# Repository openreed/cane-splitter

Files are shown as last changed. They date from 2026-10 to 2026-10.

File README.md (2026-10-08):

# Cane splitter — single-file OpenSCAD model

[中文打印与装配说明](README_CN.md)

All active CAD is in **`cane-splitter.scad`**, with BOSL2 `std.scad` and `screws.scad` for real M4 screw threads, as used by the neighboring reed-guillotine. Install BOSL2 in the OpenSCAD library path. Use the Manifold geometry backend. Select `oboe` for three ways or `bassoon` for four. Three main PETG parts: blade grip, stud-located guide lid with recessed M4 screws, and a threaded protective cap/palm pad.

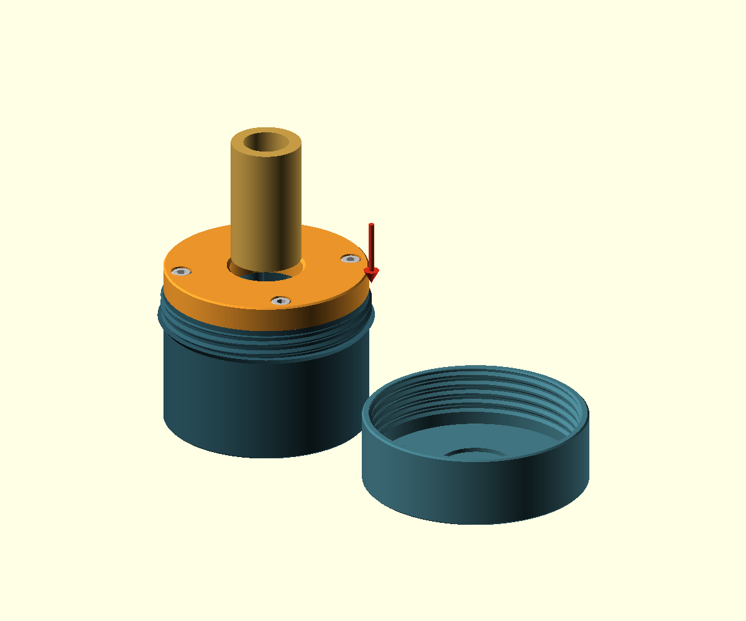
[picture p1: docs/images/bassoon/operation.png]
Top-down cane feed


Cane enters **from the top and moves downward**. The orange-red bevel is the cutting edge; the back extends outward/downward. The earlier incline was reversed and presented a blunt short end to top-down feed. This revision corrects that geometry.

Each complete blade is clamped by one **M2.5 ×10 screw through its round-bottom side notch**, plus washer and captured nut. The slot supports the sides; the screw clamps the printed cheeks and provides positive metal retention. The orange guide lid uses M4 ×12 socket-head screws directly in modeled M4 ×0.7 blind threads. No lid nuts or washers. Three sets per oboe unit; four per bassoon. No blade cutting, drilling or custom metal.

The Ø4.4 mm central guide is 12.3 mm high for oboe and 16.2 mm for bassoon, projecting 6 mm above the fin roots, with a 0.6 mm rounded top edge. One hub/spoke footprint is merged and given 0.8 mm concave root fillets; the rectangular spoke ends are buried at the axis. This gives continuous bottom transitions without exposed square root corners. See the [bottom view](docs/images/oboe/body_bottom.png) and [root detail](docs/images/oboe/root_detail.png). The orange lid guides the cane outside diameter.

Blade clamp holes now lie in straight 8 mm-thick outer support webs, continuous from the bed to the top, instead of raised cylindrical ears. The 3.2 mm central fins and cane exits remain clear. This removes the unsupported local clamping projections when printing upright.

A 0.6 mm ×45° chamfer runs around the orange lid upper edge, body bottom edge and both outer edges of the threaded palm cap. Set `cfg_edge_chamfer` or `--edge-chamfer`; `edge_chamfer_max` derives the limit from the actual counterbore clearance, body wall and cap opening wall, retaining a 0.4 mm lid lip and 1.2 mm shell wall. The current calculated limit is about 1.2 mm. The lid underside retains its flat body seating face.

The orange lid locates on coaxial hollow round studs, Ø7 ×2.5 mm, with 0.4 mm tip chamfers. Bottom sockets are Ø7.3 ×2.8 mm. Its 9 mm thickness leaves a 1.9 mm floor between these sockets and Ø7.6 ×4.3 mm head counterbores. M4 socket heads sit 0.3 mm below the top. Nominal screw engagement is 9.8 mm with 2.2 mm tip clearance. The screw mounts have one D-shaped footprint: a rounded inner end and a 9 mm-wide rectangular wall embedded in the body shell, extruded from the bed to the top. `ring_bolt_r` currently equals `body_r-6`; moving the screw inward automatically lengthens that wall while updating all matching stud and lid holes. See the [inward-position example](docs/images/oboe/ring_mount_inward.png), using body_r −10 and a 1.0 mm chamfer. The optional `connection_coupon` checks the actual PETG/M4 fit. Default BOSL2 internal tolerance is 8G with `$slop=0.04` (0.16 mm added diameter).

The protective cap uses a single-start right-hand trapezoidal thread, pitch 3.6 mm, depth 1 mm and approximately 2.2 engaged turns. An integral annular shoulder stops the cap before it can load the internal screw heads. No snap clips or friction pads. Default radial/axial fit allowances are 0.30/0.15 mm.

- Oboe body including shoulder: Ø63.1 ×50.4 mm including locating studs; stored: Ø66.7 ×62.9 mm. Default OD10, range 9.5–11.5 mm.
- Bassoon body including shoulder: Ø76.9 ×52.6 mm including locating studs; stored: Ø80.5 ×65.1 mm. Default OD25, range 23–27 mm.
- All print parts fit a 180 mm printer. Start with knot-free tubes at least 80 mm long and an inner bore of at least 5.5 mm. Start the splits with the palm pad, then draw the emerging strips evenly from below; short cane can be started and finished along the grain by hand.

Blade dimensions follow the current neighboring `reed-guillotine`: 39 ×19.4 ×0.23 mm, notch width 3/depth 3.8/edge distance 9.6 mm, backing width 7 and total thickness **0.53 mm** (0.23 +0.30). Actual marketplace blades can differ. Measure before printing; the fit coupon checks face and backing slots. For example, [Excel #9](https://excelblades.com/products/9-single-edge-razor-blades) lists a different .040″ backing.

Print body upright, guide flat, cap palm face down/open side up. Suggested PETG starting settings: 0.4 mm nozzle, 0.15 mm body layers for M4 threads, 0.20 mm for other parts, 5 walls, 5 top/bottom layers, 40–50% infill. Inspect grooves, small nut-pocket bridges and threads in the slicer. Install and tighten notch clamps before the guide ring. Tune thread clearance rather than forcing a tight cap.

```sh
python3 render.py oboe
python3 render.py oboe --parts connection_coupon
python3 render.py bassoon
python3 render.py bassoon --cane-diameter 27 --parts locking_ring,palm_cap
python3 render.py bassoon --preview operation --output docs/images/bassoon
python3 scripts/check_meshes.py 3D_files/oboe 3D_files/bassoon
python3 scripts/check_model.py
python3 scripts/check_backends.py
```

Print STLs are under `3D_files/oboe/` and `3D_files/bassoon/`. Legacy `obeh`/`bsn` command aliases use the same single source. Export defaults to Manifold and rejects errors/warnings; pass `--backend CGAL` for CGAL or older releases without Manifold support. Assemblies contain reference metal and are not printable parts. Thread face winding, coplanar body tops and coincident slot ends have been corrected. Delivered meshes and previews now use Manifold. Circular features use the current source settings: `$fa=1`, `$fs=0.1`, `$fn=0`; fixed-segment quality overrides have been removed. Manual cap helices follow the same resolution. Both instruments pass strict mesh and assembly checks at this resolution, including locating studs, real M4 thread motion and head counterbore clearance. `check_backends.py --compare-cgal` optionally compares CGAL, which can be slow at this resolution. The detached cap is shown open-side up to expose its thread.

All printed meshes are checked for oriented manifold edges, non-degenerate triangles, positive volume and connected solids. Model checks cover notch retention, hardware solids, cap unscrewing, ideal exit clearance and first top-down contact on the bevel. Actual splitting force, grain tracking, clamp creep and thread life remain untested. See [design notes](docs/design.md) and the validation reports.

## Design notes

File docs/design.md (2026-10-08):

# Revised mechanical design

## Source and simplicity

All active geometry and parameters are in one `cane-splitter.scad`, with a single instrument selector. The three printed parts are unchanged in count. `render.py` is optional batch export; Python scripts inspect artifacts. No product-specific SCAD wrappers or instrument-specific source tree is needed. BOSL2 std.scad/screws.scad provide the real metric screw geometry, matching the neighboring reed-guillotine workflow. Prior historical archives are left untouched.

## Cutting orientation

Let u run along the 39 mm blade edge and v from edge toward backing. The corrected radial/height transformation is:

`r = 2.5 + u*sin(a) + v*cos(a)`

`z = edge_inner_z + u*cos(a) - v*sin(a)`

At a fixed cane radius, positive v puts the unsharpened material BELOW the cutting edge. The u=L short end is outside the maximum cane radius by 1 mm. Thus a top-down ray hits v=0, not the blunt short end. The earlier transformation put the back on the incoming side and was wrong for top-down feeding. No reversal of user feed direction is required.

The edge is modeled with a finite 0.01 mm tip thickness widening to the nominal face thickness over 0.7 mm. Orange-red bevel and gray blade body are disjoint reference volumes sharing one boundary, not overlapping colored skins. Printed exports omit all reference metal and arrows. Support fins begin 0.8 mm radially behind the edge. The Ø4.4 mm central guide projects 6 mm above the support-fin roots: 12.314 mm overall for oboe and 16.169 mm for bassoon. A 0.6 mm top-edge radius is generated by one revolved profile. The complete hub/spoke footprint is merged in 2D, with spoke ends extending to the axis, then BOSL2 round2d(ir=0.8) forms the concave root transitions. A wider XZ mask clips that footprint to the blade-support heights; the normal cutting fins retain their 3.2 mm width. This replaces the exposed rectangular inner ends with a continuous rounded bottom outline. The projection is much shorter than the original approximately 40 mm unsupported neck; the orange lid locates the cane outside diameter.

## Positive blade fixing

The blade profile and notch dimensions are copied from the current adjacent `reed-guillotine` parameters and notch module. Each notch comprises a rectangular opening and a semicircular root: width 3 mm, total depth 3.8 mm, center 9.6 mm behind the edge. The root center is 3.8 −3/2 =2.3 mm from the short end, so the M2.5 screw is placed there, not at the midpoint of a rectangular approximation.

One M2.5 ×10 socket screw, washer and captured nut per blade passes perpendicular to the blade plane through the outer notch. The screw hole is inside a straight 8 mm-thick outer fin segment, spanning from the bottom plane to the body top. Its inner radial edge is 3.8 mm inward from the screw centre and remains outside the cane exit. This replaces the former transverse cylindrical boss with material continuously supported during upright printing. The two cheeks retain the same 8 mm span, 2.8 mm hole and nut pocket; existing M2.5 ×10 hardware still fits. The nut is loaded on the positive tangential side with the guide removed. Tightening compresses the printed cheeks against the blade. The metal shank provides a fallback axial stop even if clamping friction relaxes. Actual tightening force and PETG creep must be tested; no torque rating is claimed.

The full blade and backing guides are swept VERTICALLY upward from the measured envelope. This permits straight insertion while keeping the outer shell thick; sweeping along the tilted long edge would have thinned the upper wall. The shaft is installed only after blade insertion. The side slots alone are not relied on for retention. Removing a blade requires releasing its clamp.

Total backing thickness defaults to 0.53 mm because the current guillotine blade module models `back_clamp_thickness + blade_thickness`, with values 0.30 and 0.23 mm. This is a project assumption, not a universal .009 specification. Other brands, including [Excel #9](https://excelblades.com/products/9-single-edge-razor-blades), list other backing thicknesses. Measure actual blades and adjust.

## Threaded cap and guide

The large cylindrical cap has a single-start, right-hand trapezoidal thread, pitch 3.6 mm, depth 1 mm, with broad roots/crests, approximately 45-degree flanks and tapered entry/exit. The male segment is 8 mm long; about 2.2 turns engage. Radial/axial fit defaults to 0.30/0.15 mm. The helix is an explicitly closed, triangulated polyhedron, not a zero-thickness surface. The sweep faces, including both end caps, follow OpenSCAD’s clockwise-from-outside convention. The previous sweep was consistently inside out: CGAL produced the intended bounded shape, while Manifold interpreted its Boolean operations incorrectly. Positive signed-volume and oriented-edge checks now validate the standalone sweep before it is unioned with the body or subtracted from the cap. All circles use the current source settings $fa=1, $fs=0.1 and $fn=0. The manual sweep derives its angular sample count from the same rule as circular primitives; at the current cap radii it uses 360 samples per turn. No fixed low-resolution facet count overrides these settings. A 0.73-degree angular phase keeps sweep facets apart from cylindrical facet seams.

The cap thread is cut in assembled world coordinates using the same helix as the male thread. The whole cap is then inverted for printing. This avoids accidentally generating an incompatible handedness. Unscrewing is counterclockwise viewed from the external palm face, with upward motion equal to pitch times revolutions. The cap underside contains a shallow cane-centering cup; the palm face is flat and 4 mm thick. Internal cup and hardware have free clearance in the stored pose.

The lid screw seats use a single extruded D-shaped polygon: a 4.5 mm-radius inner semicircle and a 9 mm-wide rectangular wall running from the screw axis to body_r −wall/2. Its arc follows the common circular precision. The wall overlaps the outer shell continuously from z=0 to the body top. Moving ring_bolt_r inward automatically extends this wall instead of leaving a circular post disconnected from the shell above the bottom floor. Geometry assertions keep the inner end outside the cane exit and the rectangular end outward of the screw axis.

The orange guide lid seats on one coaxial hollow round stud at each fixing point: three for oboe, four for bassoon. Each stud is Ø7 ×2.5 mm, with a 0.4 mm tip chamfer, overlapping the existing post by 0.02 mm. The receiving bottom sockets are Ø7.3 ×2.8 mm with a small entry chamfer. Their diameter clearance is 0.30 mm and axial clearance 0.30 mm. The studs locate the lid before screws are inserted and resist lateral displacement without extra separate pins.

M4 ×12 ISO 4762 socket-head screws replace the former M3 screw/nut/washer stacks. A BOSL2 screw_hole("M4", thread=true, tolerance="8G") cuts an actual right-hand M4 ×0.7 blind thread through each stud into the body. Hole depth is 12 mm from the stud top; the default printing slop is 0.04 mm, which BOSL2 enlarges into 0.16 mm added diameter. A matching 6g screw reference is phased using the thread centre heights and BOSL2 internal half-pitch profile shift; screws are real threaded solids in inspection views, not cylindrical stand-ins.

The lid is 9 mm thick. Its Ø4.4 mm shaft clearance hole connects a Ø7.6 ×4.3 mm counterbore above and the locating socket below. The internal floor between the two larger recesses is 1.9 mm thick; the head-bearing plane is 4.7 mm above the body seat. A Ø7 ×4 mm socket head sits 0.3 mm below the lid surface. Nominal thread engagement is 9.8 mm, with 2.2 mm axial clearance at the blind bottom. The M4 connection has no separate washer or nut. A two-block connection_coupon reproduces the stud, socket, thread and counterbore for trial printing.

An integral printed annular shoulder below the large cap thread provides a positive storage stop. Its 2.4 mm high taper is printable and its hollow centre leaves all cane exits open. The cap interior was raised to clear the thicker lid and its centering lip: 2 mm above the lid, leaving 0.5 mm below the 1.5 mm-deep lip. Overall stored height grows only 2 mm. No clips, interference ribs or decorative grip cuts interrupt the cap thread. Thread fit and wear require physical testing.

## Geometry and printing

Outer exposed rims currently use a 0.6 mm ×45° chamfer. Closed triangular revolved cutters extend beyond the solid boundary and use the shared circular precision. The lid underside remains flat. The upper limit is the minimum of: body_r −ring_bolt_r −counterbore_radius −0.4; body_wall −1.2; cap_outer_radius −cap_opening_radius −1.2; and half the lid/cap heights. The current limit is about 1.2 mm. With ring_bolt_r =body_r −6 and the current chamfer, the lid counterbore outer top lip is 1.6 mm, the body bottom wall 2.4 mm and the cap opening wall about 1.8 mm. A small numerical tolerance is applied only to the assertion comparison. Increasing the radial hole setback can increase the lid limit; the body and cap limits still apply.

Body wall 3 mm; central fins 3.2 mm; outer clamping webs 8 mm; cap root wall at least 2.5 mm. The body is printed upright, ring flat and cap palm face down/open cup up. The support fins retreat outward with height, avoiding the large underside overhang a mirrored blade seat would otherwise cause. Body/cap threads have printable flank slopes. Nut pockets and horizontal clamp holes use short bridges; inspect the slicer. The cap's internal centering lip rises directly from the solid palm floor. Body layers of 0.15 mm are suggested for the 0.7 mm-pitch M4 threads. The lid socket-to-shaft transition bridges only about 1.45 mm radially; no support should be inserted in the threaded holes or locating sockets.

The rim, full-height fin ends and guide posts extend 0.3 mm beyond the intended top, are united, then cut to one common top plane. This avoids joining independently coincident top faces and preserves the body height and shape. The backing-slot cutter overruns the face-slot cutter at its ends; the actual face/back slot widths remain independently specified. The reference blade now extrudes its thin face, bevel and thicker backing from one stepped profile, eliminating overlapping end faces.

Each main part is explicitly rendered as a complete solid in preview. Blade bevel colors are separated by solid intersections/differences. This removes overlapping preview skins and avoids using transparency to expose internals. A section view is intentionally a CUT solid; its opened appearance does not mean a printable component has missing faces.

## Verification

`check_meshes.py` rejects collapsed or zero-area facets, duplicate faces, nonfinite coordinates, edges without exactly two oppositely oriented incident faces, nonpositive volume and wrong connected components. Main printed parts must each be one closed component on z=0; the blade coupon intentionally contains three separate blocks and the connection coupon two. All fit in the 180 mm build volume.

`check_model.py` also checks blade, screw, nut and washer solids separately. Top-down rays across 19 radii per instrument must hit the modeled edge first; neighboring fin surfaces must remain below it. The script also casts vertical rays through six columns in the outer clamping webs and requires uninterrupted material from z=0.2 mm to just below the clamp hole. These checks would reject the former raised ears, whose columns have a gap above the bottom floor. Three more rays through the centre and a sector bisector check that the guide is continuous from the bed and has the expected flat/rounded top. Its projection above the roots is limited to two diameters. Additional rays test material in the rounded root transitions on both sides of every fin and require clearance at a 2.75 mm radius in every exit-sector bisector. The script tests blade fit, straight insertion at six positions, metal notch retention after axial displacement, conservative exit clearance, guide limits and an invalid notch input. New checks cover seven vertical lid insertion positions, deliberate locator misalignment, recessed head/shaft clearance, positive counterbore-floor contact, six M4 thread-unscrewing positions and a deliberately wrong M4 thread phase. The wrong-phase control must intersect material so a plain cylindrical bore cannot pass as a threaded hole.

Thread checks cover the stored pose, every one-eighth turn from 0 to 2.5 revolutions, and 0.1 revolution. They compare the actual cap and male thread with a solid cylindrical envelope enclosing the grip, blades and guide, plus the stop shoulder and explicit protruding fasteners. A separate downward-displacement check must collide with the shoulder to verify the positive stop. This conservative bound is stronger than relying on empty internal pockets. Blade/cane tests omit the exterior thread, which lies entirely outside their bounded envelopes. A deliberately wrong thread phase must collide, so an empty test cannot pass merely because the thread is absent.

Diagnostic intersections can contain intended washer/boss, ring/rim or cap/shoulder contact surfaces. These are not physical part exports. The checks measure bounded intersection volume with a 0.0001 mm³ allowance for float32 STL rounding; a deliberately wrong thread phase and a downward stop violation must exceed that allowance. Every physical printed part, metal reference and standalone thread sweep must pass the strict closed-solid mesh checks.

`check_backends.py` validates the actual Manifold exports of both instruments using the current source circular settings, including both coupons. An explicit --compare-cgal option compares dimensions and volumes with CGAL; this is optional because the higher resolution makes CGAL considerably slower. docs/backend-validation.json records current Manifold results and local timings. render.py defaults to Manifold for STL and colored PNG generation, with an explicit --backend CGAL option. The former fixed-segment --quality override was removed. Measurements used the locally installed OpenSCAD 2025.12.07 and BOSL2; timings are specific to this machine and resolution.

The current full assembly results are recorded in docs/model-validation.json; the chamfer summary is derived from those results in docs/chamfer-validation.json. The mounting-wall rays must find uninterrupted material from the bed to the body top on both sides of each screw seat. docs/ring-mount-validation.json additionally checks inward movement by setting the screw radius to body_r −10, rendering a 1.0 mm chamfer, and rejecting incompatible clearances.

Digital checks do not establish splitting force, clamp preload, cover friction, thread fatigue or behavior of oval/nodal cane. Start with a fit coupon and waste cane before relying on the tool.

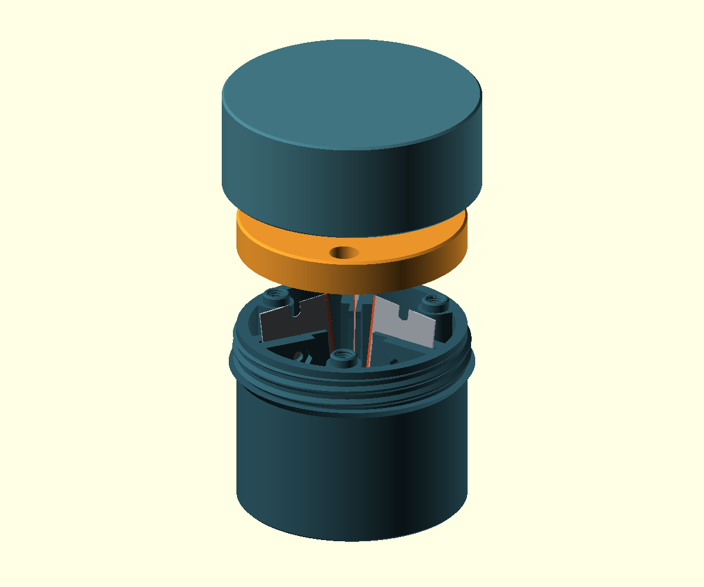
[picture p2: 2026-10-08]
docs/images/oboe/exploded.png

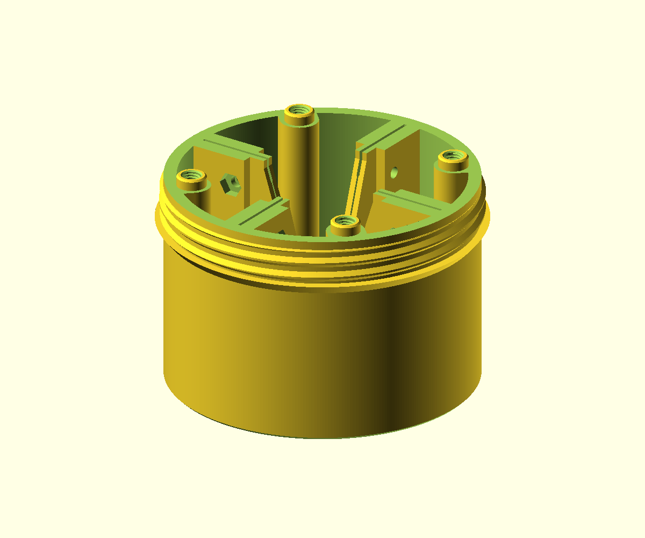
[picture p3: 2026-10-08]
docs/images/bassoon/body.png

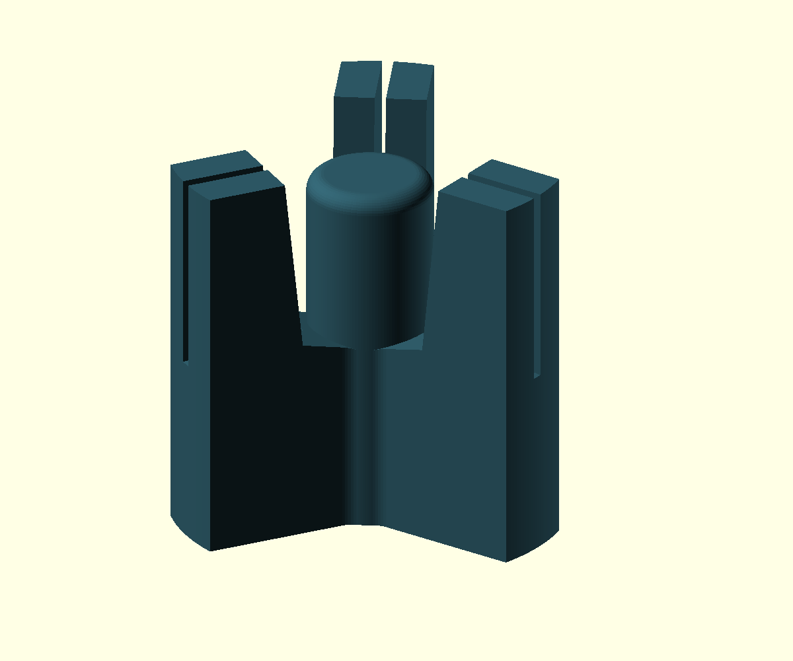
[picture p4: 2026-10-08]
docs/images/oboe/root_detail.png

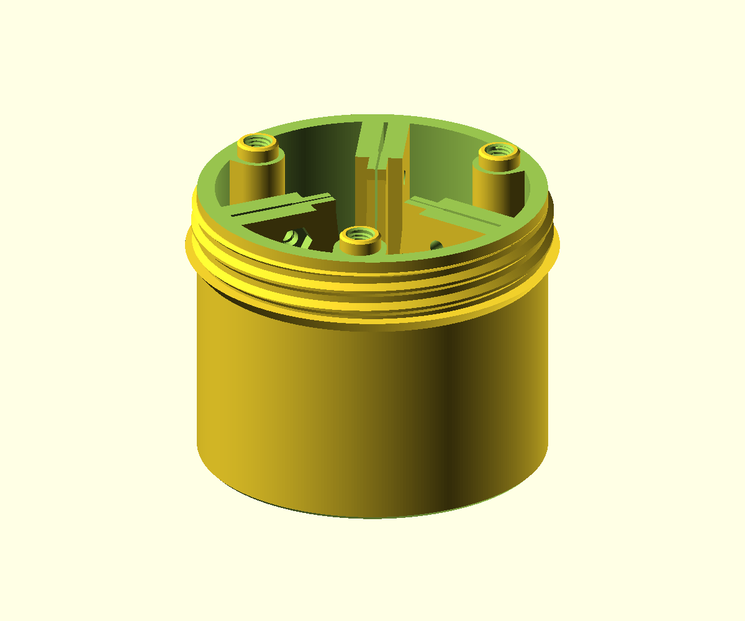
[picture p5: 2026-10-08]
docs/images/oboe/body.png

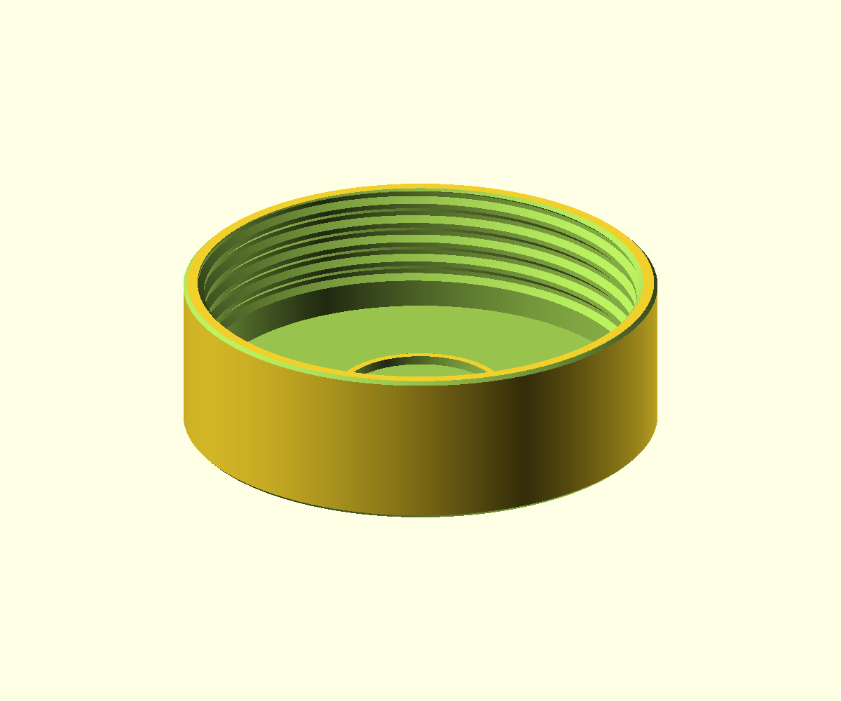
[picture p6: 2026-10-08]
docs/images/bassoon/palm_cap.png

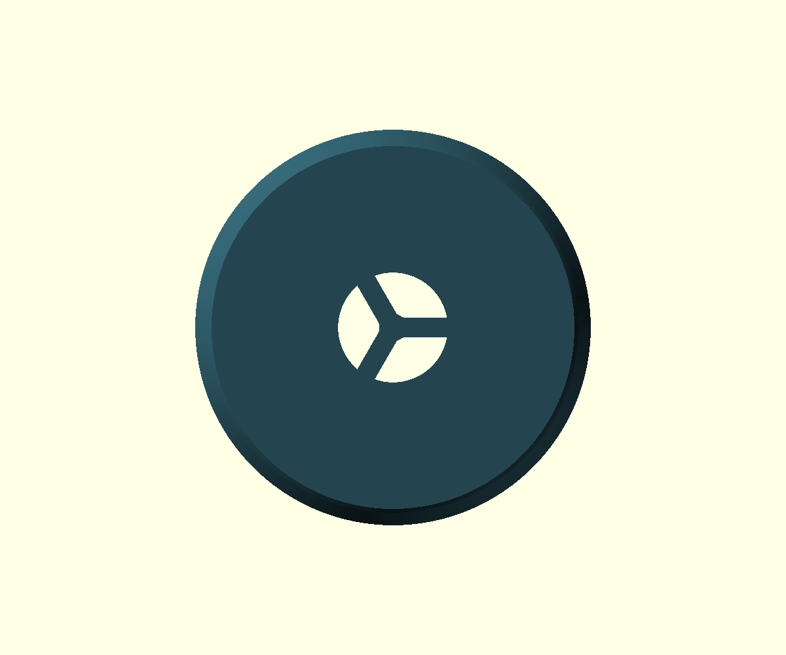
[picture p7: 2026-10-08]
docs/images/oboe/body_bottom.png

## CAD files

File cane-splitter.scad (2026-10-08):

// OpenReed 芦苇管三分／四分器，建模代码集中于一个文件 | Single-source cane splitter.
include <BOSL2/std.scad>
include <BOSL2/screws.scad>

// 圆弧精度按 reed-guillotine 统一设置；不使用固定圆周分段数覆盖它。
// Shared circular precision; $fn=0 keeps $fa/$fs effective.
// 圆弧分段角度设置 | Angular resolution setting for circles
$fa = 1;
// 圆弧分段长度设置 | Segment-length resolution setting for circles
$fs = 0.1;
// 使用角度与长度自动分段 | Use automatic angular/length tessellation
$fn = 0;
// 尺寸单位为毫米；芦苇从 +Z 进入，刃口朝 +Z | Millimetres; top-down feed.

/*[输出 | Output]*/
// 乐器：双簧管三等分，巴松四等分 | Oboe: three sectors; bassoon: four sectors
cfg_instrument = "oboe"; // [oboe,bassoon]
// 输出零件或查看方式 | Output part or inspection view
cfg_part = "exploded"; // [assembly,exploded,section,operation,body,locking_ring,palm_cap,coupon,connection_coupon,print_plate]
// 装配图中显示刀片和标准件 | Show blades and standard hardware in assembly views
cfg_show_hardware = true;

/*[基本参数 | Basic Parameters]*/
// 芦苇管外径；0 使用默认值：双簧管 10、巴松 25 mm | Cane OD; 0 selects 10 mm oboe / 25 mm bassoon
cfg_cane_diameter = 0;
// 顶盖上沿、主体底沿及掌压盖外沿的 45° 倒角宽度 | 45-degree outer-edge chamfer width on the lid, body base and palm cap
cfg_edge_chamfer = 1;

/*[刀片参数 | Blade Parameters]*/
// 完整 009RD 刀片长度，沿刃口方向 | Complete blade length along the cutting edge
cfg_blade_length = 39;
// 刀片总宽度，从刃口到刀背 | Overall blade width from edge to back
cfg_blade_width = 19.4;
// 刀片薄钢片厚度 | Thickness of the thin steel blade
cfg_blade_thickness = 0.23;
// 刀背总厚度，复用 reed-guillotine 的 0.23 + 0.30 mm | Total backing thickness: 0.23 + 0.30 mm
cfg_back_thickness = 0.53;
// 加厚刀背区域的宽度 | Width of the reinforced backing
cfg_back_width = 7;
// 两个短端圆底缺口的总深度 | Overall depth of each round-bottom end notch
cfg_notch_depth = 3.8;
// 侧缺口宽度，也是圆底直径 | End-notch width and rounded-root diameter
cfg_notch_width = 3.0;
// 缺口中心到刃口的距离 | Distance from the cutting edge to the notch centre
cfg_notch_from_edge = 9.6;

/*[公差 | Tolerances]*/
// 刀身槽增加的总宽度；每侧为此值的一半 | Added blade-slot width, half on each side
cfg_blade_slot_clearance = 0.16;
// 刀背槽增加的总宽度；每侧为此值的一半 | Added backing-slot width, half on each side
cfg_back_slot_clearance = 0.20;
// 保护盖内螺纹的径向间隙 | Radial clearance of the cap thread
cfg_thread_radial_clearance = 0.30;
// 保护盖内螺纹牙槽每侧的轴向间隙 | Axial clearance on each flank of the cap thread
cfg_thread_axial_clearance = 0.15;

/*[导向盖连接参数 | Guide Lid Connection Parameters]*/
// 积木式圆榫外径；中心同时容纳 M4 螺纹 | Round locating-stud diameter, with M4 thread at its centre
cfg_locator_diameter = 7;
// 圆榫突出主体顶面的高度 | Locating-stud height above the body seating face
cfg_locator_height = 2.5;
// 榫孔增加的直径间隙 | Added diameter clearance of each locating socket
cfg_locator_diameter_clearance = 0.30;
// 榫孔增加的深度间隙 | Added depth clearance of each locating socket
cfg_locator_depth_clearance = 0.30;
// M4 内螺纹的打印补偿量；BOSL2 实际直径增加 4 倍此值 | BOSL2 print slop; diameter increases by four times this value
cfg_m4_thread_slop = 0.04;

/*[Hidden]*/
// 检查项名称，留空时输出正常模型 | Diagnostic name; empty selects the normal model
cfg_check = "";
// 检查装刀路径时的竖直抬升量 | Vertical displacement for blade-insertion checks
cfg_insertion = 0;
// 检查保护盖旋开时的圈数 | Revolutions for cap-unscrewing checks
cfg_cap_turns = 0;

// 内部参数 | Internal Parameters
// 布尔运算切除体的越界量 | Overrun of Boolean cutters
eps = 0.02;
// 刀片数量与等分数量 | Blade and sector count
n = cfg_instrument == "oboe" ? 3 : 4;
// 实际采用的芦苇外径 | Effective cane outside diameter
cane_d = cfg_cane_diameter == 0 ? (n==3 ? 10 : 25) : cfg_cane_diameter;
// 支持的最小芦苇外径 | Minimum supported cane OD
cane_min = n==3 ? 9.5 : 23;
// 支持的最大芦苇外径 | Maximum supported cane OD
cane_max = n==3 ? 11.5 : 27;
// 刀片长度 | Blade length
L = cfg_blade_length;
// 刀片宽度 | Blade width
W = cfg_blade_width;
// 刀身厚度 | Blade thickness
T = cfg_blade_thickness;
// 刀背总厚度 | Total backing thickness
back_t = cfg_back_thickness;
// 加厚刀背区域宽度 | Reinforced backing width
back_w = cfg_back_width;
// 侧缺口总深度 | Overall end-notch depth
notch_d = cfg_notch_depth;
// 侧缺口宽度 | End-notch width
notch_w = cfg_notch_width;
// 缺口中心距刃口的距离 | Notch-centre distance from the edge
notch_v = cfg_notch_from_edge;
// 刃口内端距中心轴的距离 | Radius of the inner cutting-edge end
inner_r = 2.5;
// 中心短导向柱半径，与三／四条支撑筋相连 | Short central guide radius, joined to all fins
hub_r = 2.2;
// 刀背内端的高度基准 | Height datum at the inner back end
seat_z = 5;
// 刀座外壁厚度 | Body shell thickness
wall = 3;
// 刀座支撑筋厚度 | Blade-support fin thickness
fin_t = 3.2;
// 支撑筋相对刃口的径向退让 | Radial setback of the support behind the edge
edge_exposure = 0.8;
// 刀片相对竖直方向的倾角 | Blade inclination from vertical
a = asin((cane_max/2+1-inner_r)/L);
// 刃口内端高度 | Inner cutting-edge height
edge_inner_z = seat_z+W*sin(a);
// 支撑筋中心端的顶部高度 | Top height at the central end of each support fin
fin_root_z = edge_inner_z-0.8;
// 导向柱高于支撑筋根部的长度 | Guide projection above the support-fin roots
hub_projection = 6;
// 中心导向柱总高度 | Overall central guide height
hub_h = fin_root_z+hub_projection;
// 中心短柱顶部圆角半径 | Top-edge rounding radius of the short hub
hub_round = 0.6;
// 导向柱与支撑筋之间的平面内凹圆角半径 | Concave plan fillet between the hub and support fins
fin_root_round = 0.8;
// 刃口外端半径 | Outer cutting-edge radius
edge_outer_r = inner_r+L*sin(a);
// 刃口外端高度 | Outer cutting-edge height
edge_outer_z = edge_inner_z+L*cos(a);
// 刀背外端半径 | Outer backing radius
outer_back_r = edge_outer_r+W*cos(a);
// 刀座外壁半径，不含螺纹和台肩 | Body shell radius, excluding thread and shoulder
body_r = outer_back_r+3.5;
// 刀座总高度 | Body height
body_h = edge_outer_z+2;
// 底部出口半径 | Bottom exit radius
exit_r = cane_max/2+3;
// 导向圈中心孔半径 | Guide aperture radius
guide_r = (cane_d+1)/2;
// 橙色导向盖厚度，默认沉孔和榫孔之间保留 1.9 mm | Guide lid thickness; 1.9 mm floor between counterbore and socket
ring_h = 9;
// 导向盖固定螺丝及定位圆榫的分布半径 | Shared placement radius of lid screws and locating studs
ring_bolt_r = body_r-6;
// 导向盖固定座内端半圆的半径，也是连接墙的半宽 | Rounded mount-end radius and half-width of its connecting wall
ring_post_r = 4.5;
// 导向盖连接墙的外端，伸入主体侧壁中部 | Outer end of the lid mounting wall, embedded in the body shell
ring_wall_end = body_r-wall/2;
// ISO 4762 M4 螺丝的杆长 | ISO 4762 M4 screw length beneath the head
ring_screw_L = 12;
// M4 粗牙螺距 | M4 coarse thread pitch
ring_screw_pitch = 0.7;
// M4 螺丝头外径 | M4 socket-head diameter
ring_head_d = 7;
// M4 螺丝头高度 | M4 socket-head height
ring_head_h = 4;
// 橙色导向盖的螺丝通孔直径 | Lid screw clearance-hole diameter
ring_hole_d = 4.4;
// 螺丝头沉孔直径 | Screw-head counterbore diameter
ring_counterbore_d = ring_head_d+0.6;
// 螺丝头沉孔深度，使头部低于顶面 0.3 mm | Counterbore depth; head sits 0.3 mm below the lid top
ring_counterbore_depth = ring_head_h+0.3;
// 螺丝头的承压面相对主体顶面的高度 | Screw-head bearing plane above the body seating face
ring_head_seat = ring_h-ring_counterbore_depth;
// 主体内 M4 盲螺孔从圆榫顶部向下的深度 | M4 blind-hole depth measured down from the stud top
ring_thread_depth = 12;
// 标准螺丝参考模型的旋合相位，补偿 BOSL2 内外螺纹的半牙相位差 | Reference screw phase, accounting for BOSL2's half-pitch internal profile shift
ring_screw_spin = 360*((ring_head_seat-cfg_locator_height-eps/2+(ring_thread_depth-ring_screw_L)/2)/ring_screw_pitch-0.5);
// 定位圆榫直径 | Locating-stud diameter
locator_d = cfg_locator_diameter;
// 定位圆榫突出高度 | Locating-stud projection height
locator_h = cfg_locator_height;
// 定位圆榫顶部导入倒角高度 | Locating-stud lead-in chamfer height
locator_chamfer = 0.4;
// 刀片夹紧螺丝直径，采用 M2.5 | Blade clamp screw diameter: M2.5
clamp_d = 2.5;
// 刀片夹紧螺丝通孔直径 | Blade clamp clearance-hole diameter
clamp_hole_d = 2.8;
// ISO 4762 M2.5 螺丝的杆长 | ISO 4762 M2.5 screw length beneath the head
clamp_L = 10;
// M2.5 六角螺母对边尺寸 | M2.5 nut width across flats
clamp_nut_af = 5;
// M2.5 六角螺母厚度 | M2.5 nut thickness
clamp_nut_h = 2;
// 外端圆底缺口中心沿刃口的位置 | Position of the outer notch root along the edge
clamp_u = L-(notch_d-notch_w/2);
// 夹紧螺丝中心的径向与高度坐标 | Radial and height coordinates of the clamp screw
clamp_p = [inner_r+clamp_u*sin(a)+notch_v*cos(a),
           edge_inner_z+clamp_u*cos(a)-notch_v*sin(a)];
// 支撑筋外段的夹紧厚度，沿打印高度保持一致 | Constant thickness of the outer clamping web
clamp_span = 8;
// 螺孔中心到夹紧厚壁内缘的距离 | Screw-centre setback from the inner edge of the thick web
clamp_edge_margin = 3.8;
// 夹紧厚壁的内缘半径，避开苇片出口 | Inner radius of the clamping web, outside the cane exits
clamp_inner_r = clamp_p[0]-clamp_edge_margin;
// 单线右旋梯形螺纹的螺距 | Pitch of the single-start right-hand trapezoidal thread
thread_pitch = 3.6;
// 外螺纹径向牙高 | Radial height of the external thread
thread_depth = 1.0;
// 螺纹及其配合圆柱的统一分段数 | Shared tessellation of the thread and mating cylinders
thread_segments = circle_segments(body_r+thread_depth+cfg_thread_radial_clearance);
// 外螺纹起始高度 | Lower end of the external thread band
thread_start = body_h-10;
// 外螺纹终止高度 | Upper end of the external thread band
thread_end = body_h-2;
// 螺旋线零角度处的高度基准 | Helix height datum at zero angle
thread_phase = thread_start+thread_pitch/2;
// 内螺纹径向间隙 | Internal-thread radial clearance
thread_fit = cfg_thread_radial_clearance;
// 内螺纹每侧轴向间隙 | Internal-thread axial clearance per flank
thread_zfit = cfg_thread_axial_clearance;
// 旋紧保护盖的开口面高度 | Open-face height of the seated cap
cap_bottom = thread_start-0.5;
// 保护盖内侧掌面高度 | Inside palm-face height of the cap
cap_ceiling = body_h+ring_h+2;
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
